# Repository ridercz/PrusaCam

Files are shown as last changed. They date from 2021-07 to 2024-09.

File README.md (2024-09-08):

# PrusaCAM Timelapse Trigger

This is project for making timelapse photos of 3D printing using a common mobile phone, triggered by the printer itself using Bluetooth.

* [Prusa MK3 family](MK3) has some GPIO pins available that can be controlled using G-Code.
* [Prusa MK4 family](MK4) has I2C expansion port to which a [special board](https://help.prusa3d.com/article/gpio-module_734695) can be connected.

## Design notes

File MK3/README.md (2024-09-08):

# PrusaCam for MK3

PrusaCam for MK3 is solution for controlling mobile phones as timelapse cameras from **Prusa MK3** 3D printer by Prusa Research.

> Please note that if you have printer with the xBuddy board (MK3.5 and above), you have to use the MK4 version, not this one.

* **[PrusaCam Feather BT](PrusaCamFeatherBT)** is Bluetooth LE trigger for controlling cellphone cameras, based on _Adafruit Feather 32u4 Bluefruit LE_ board.
* **[PrusaCam ESP32 BT](PrusaCamESP32BT)** is another Bluetooth LE trigger, this time based on ESP32, which is cheaper and more easily available than the Adafruit Feather**.
* **[PrusaCAM USB](PrusaCamUSB)** is smartphone camera controller that emulates USB keyboard.

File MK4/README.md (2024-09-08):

# PrusaCam for MK4

PrusaCam for MK4 is solution for controlling mobile phones as timelapse cameras from **Prusa MK3** 3D printer by Prusa Research. This device will act as remote shutter (Bluetooth keyboard) for the mobile phone camera.

# Hardware

* [GPIO "Hackerboard" set](https://www.prusa3d.com/product/gpio-hackerboard-set/).
* Any board with ESP32 chip with Bluetooth LE capability.

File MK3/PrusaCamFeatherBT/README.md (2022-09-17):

# PrusaCam Feather BT

This is Bluetooth LE trigger for controlling cellphone cameras, based on [Adafruit Feather 32u4 Bluefruit LE](https://www.adafruit.com/product/2829).

## Instructions

* English: [How to make 3D print time lapses with your smartphone camera](https://blog.prusaprinters.org/how-to-make-3d-print-time-lapses-with-your-smartphone-camera/)
* Česky: [Jak na časosběry 3D tisků s pomocí mobilu](https://josefprusa.cz/jak-na-casosbery-3d-tisku-s-pomoci-mobilu/)

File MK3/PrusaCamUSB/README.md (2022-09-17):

# PrusaCam USB

This is smartphone camera controller that emulates USB keyboard. It's intended for any board that uses **ATmega32u4**, ie. Arduino Leonardo, Pro Micro etc. The [HID Project](https://github.com/NicoHood/HID) library is used to emulate the USB keyboard.

To use it with your cellphone, you need a way to connect your board to your phone. Common solution is "USB OTG adaptor", which will convert the MicroUSB or USB-C port of your phone to common USB type A connector. Then you'll use standard MicroUSB cable to connect the board.

I'm actively developing this project now, documentation coming soon.

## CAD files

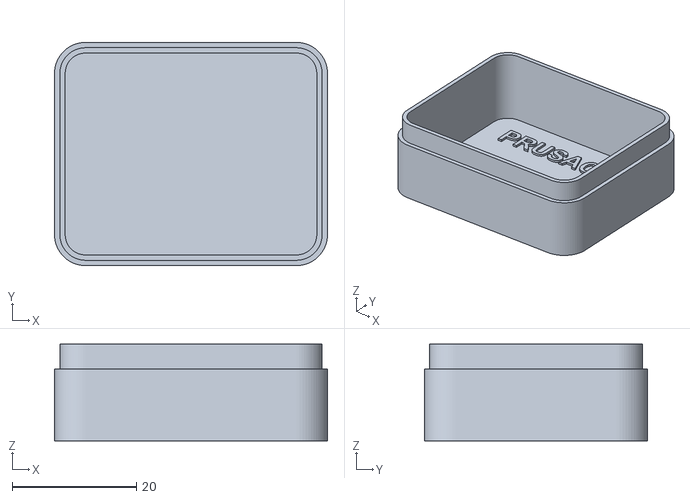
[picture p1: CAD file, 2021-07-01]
MK3/PrusaCamESP32BT/case/PrusaCamESP32BT_bottom.stl
43.9 x 35.9 x 15.6

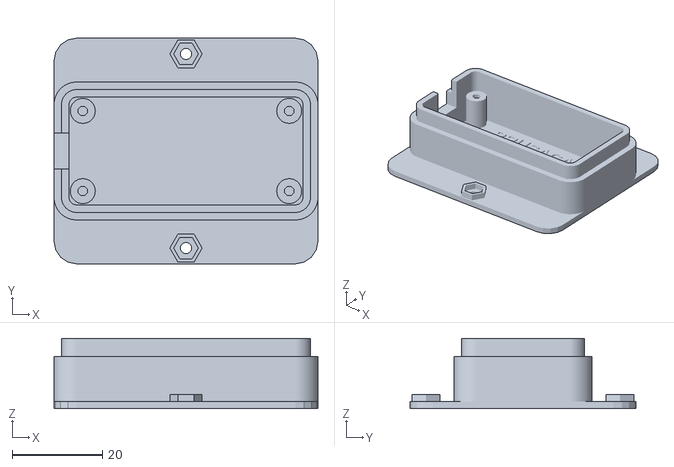
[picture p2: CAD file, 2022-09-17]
MK3/PrusaCamFeatherBT/case/PrusaCamFeatherBT_bottom_with_holder.stl
58.5 x 50.0 x 15.6

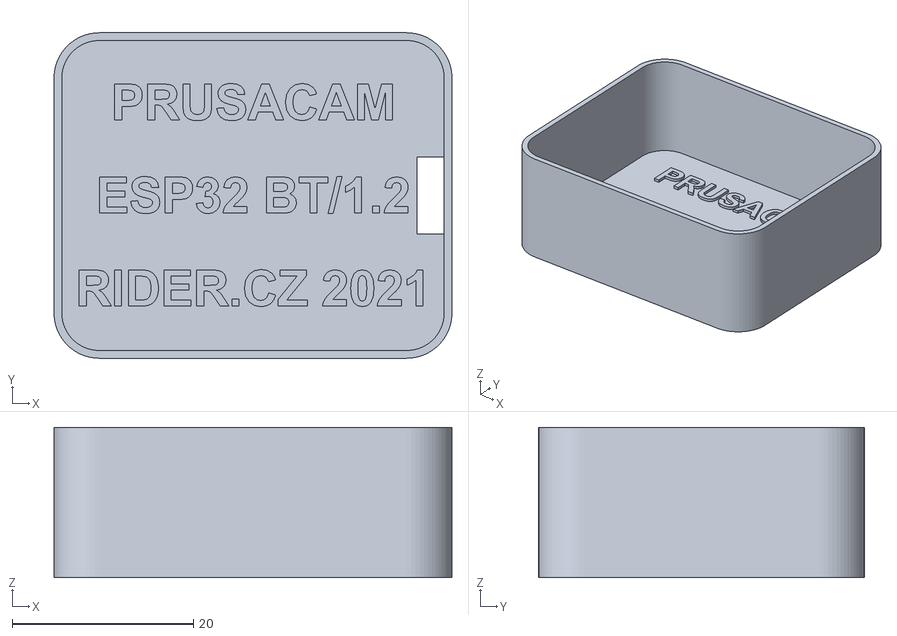
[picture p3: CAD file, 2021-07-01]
MK3/PrusaCamESP32BT/case/PrusaCamESP32BT_top.stl
43.9 x 35.9 x 16.6

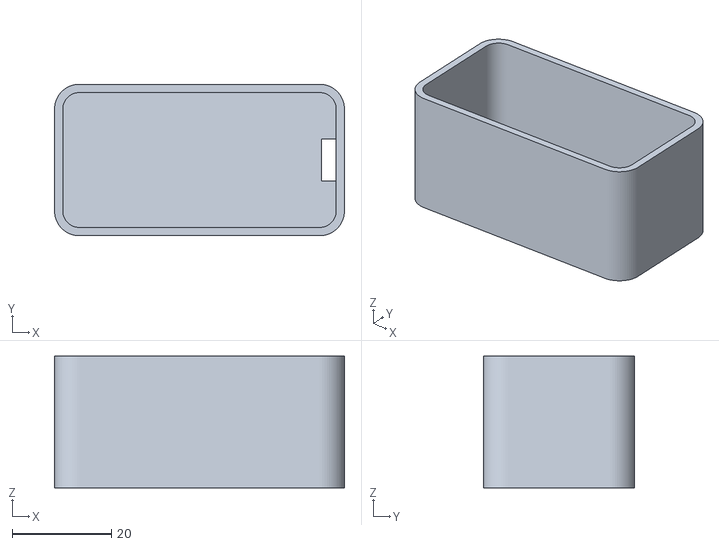
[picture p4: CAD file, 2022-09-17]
MK3/PrusaCamFeatherBT/case/PrusaCamFeatherBT_top.stl
58.5 x 30.5 x 26.6

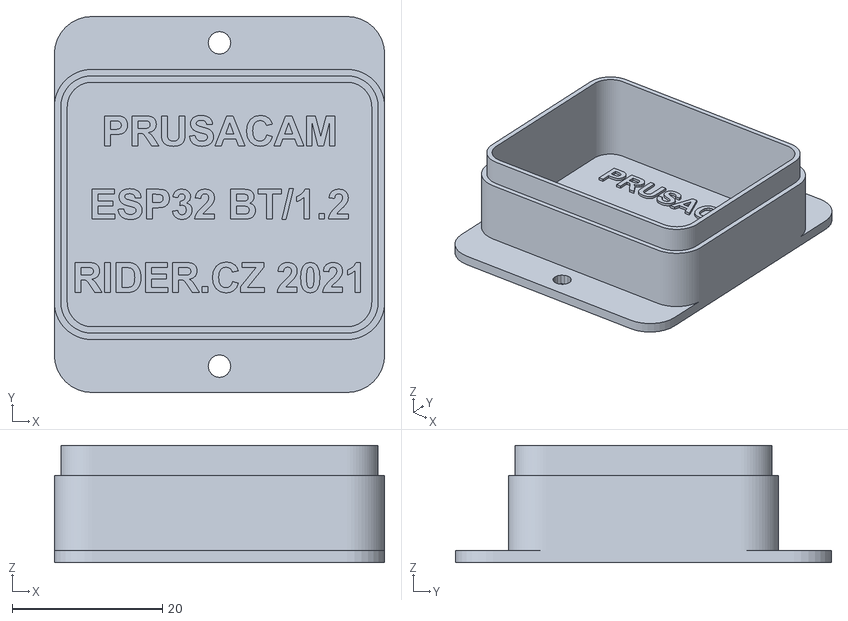
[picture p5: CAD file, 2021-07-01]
MK3/PrusaCamESP32BT/case/PrusaCamESP32BT_bottom_with_holder.stl
43.9 x 50.0 x 15.6

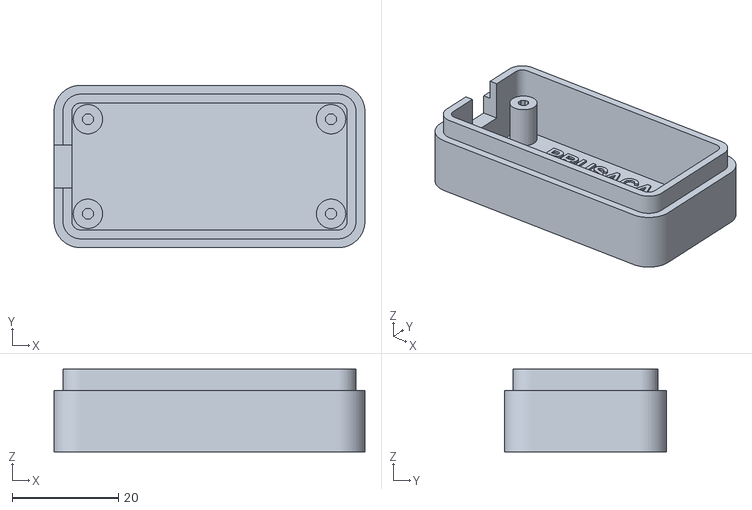
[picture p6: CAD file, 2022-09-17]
MK3/PrusaCamFeatherBT/case/PrusaCamFeatherBT_bottom.stl
58.5 x 30.5 x 15.6

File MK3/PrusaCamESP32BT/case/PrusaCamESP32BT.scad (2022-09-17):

/* [Board dimensions] */
board_size = [40, 32]; 
board_clearance = .5;
cable_size = [3, 8.5];

/* [Top part] */
top_height = 15;

/* [Bottom part] */
bottom_height = 14;
bottom_lip = 4;

/* [Holder plate] */
holder_width = 50;
holder_hole_span = 43;
holder_hole_diameter = 3;
holder_nut_diameter = 5.5;

/* [Hidden] */
wth = 1.60;
wtv = .86;
outer_radius = 5;
vsig = ["PRUSACAM", "ESP32 BT/1.2", "RIDER.CZ 2021"];
$fudge = 1;

// Render all

translate([0, 100]) bottom();
translate([0, 50]) top();
holder();

module holder() {
    holder_size = [
        board_size[0] + board_clearance + 4 * wtv, 
        holder_width, 
        wth
    ];

    bottom(hollow = true);

    difference() {
        // Plate
        translate([-holder_size[0] / 2, -holder_size[1] / 2]) rcube(holder_size, outer_radius, $fn = 32);

        // Screw holes
        for(y = [-holder_hole_span / 2, holder_hole_span / 2]) translate([0, y, -$fudge]) cylinder(d = holder_hole_diameter, h = 2 * wth + 2 * $fudge, $fn = 16);
    }
}

module top() {
    outer_size = [
        board_size[0] + board_clearance + 4 * wtv,
        board_size[1] + board_clearance + 4 * wtv,
        top_height + wth
    ];
    inner_size = [
        board_size[0] + board_clearance + 2 * wtv,
        board_size[1] + board_clearance + 2 * wtv,
        outer_size[2]
    ];
    inner_radius = outer_radius - wtv;

    // Main shape
    difference() {
        // Outer shape
        translate([-outer_size[0] / 2, -outer_size[1] / 2]) rcube(outer_size, outer_radius, $fn = 64);

        // Main hole
        translate([-inner_size[0] / 2, -inner_size[1] / 2, wth]) rcube(inner_size, inner_radius, $fn = 64);

        // Cable hole
        translate([inner_size[0] / 2 - cable_size[0], -cable_size[1] / 2, -$fudge]) cube([cable_size[0], cable_size[1], wth + 2 * $fudge]);
    }

    // Signature
    linear_extrude(wth + .4) {
        translate([0, inner_size[1] * +.3]) text(text = vsig[0], font = "Arial:bold", size = 4, halign = "center", valign = "center");
        text(text = vsig[1], font = "Arial:bold", size = 4, halign = "center", valign = "center");
        translate([0, inner_size[1] * -.3])text(text = vsig[2], font = "Arial:bold", size = 4, halign = "center", valign = "center");
    }
}

module bottom(hollow = false) {
    outer_size = [
        board_size[0] + board_clearance + 4 * wtv,
        board_size[1] + board_clearance + 4 * wtv,
        bottom_height - bottom_lip + wth
    ];
    inner_size = [
        board_size[0] + board_clearance,
        board_size[1] + board_clearance,
        bottom_height + wth + 2 * $fudge
    ];
    inner_radius = outer_radius - 2 * wtv;
    inner_lip_size = [
        board_size[0] + board_clearance + 2 * wtv,
        board_size[1] + board_clearance + 2 * wtv,
        bottom_height + wth
    ];
    inner_lip_radius = outer_radius - wtv;

    // Main shape
    difference() {
        union() {
            // Outer shape
            translate([-outer_size[0] / 2, -outer_size[1] / 2]) rcube(outer_size, outer_radius, $fn = 64);
            // Lip
            translate([-inner_lip_size[0] / 2, -inner_lip_size[1] / 2]) rcube(inner_lip_size, inner_lip_radius, $fn = 64);
        }

        // Main hole
        if(hollow) {
            translate([-inner_size[0] / 2, -inner_size[1] / 2, -$fudge]) rcube(inner_size, inner_radius, $fn = 64);
        } else {
            translate([-inner_size[0] / 2, -inner_size[1] / 2, wth]) rcube(inner_size, inner_radius, $fn = 64);
        }

    }

    // Signature
    linear_extrude(wth + .4) {
        translate([0, inner_size[1] * +.3]) text(text = vsig[0], font = "Arial:bold", size = 4, halign = "center", valign = "center");
        text(text = vsig[1], font = "Arial:bold", size = 4, halign = "center", valign = "center");
        translate([0, inner_size[1] * -.3])text(text = vsig[2], font = "Arial:bold", size = 4, halign = "center", valign = "center");
    }
}

module rcube(size, radius) {
    if(!is_list(radius)) {
        // The same radius on all corners
        rcube(size, [radius, radius, radius, radius]);
    } else if(len(radius) == 2) {
        // Different radii on top and bottom
        rcube(size, [radius[0], radius[0], radius[1], radius[1]]);
    } else if(len(radius) == 4) {
        // Different radius on different corners
        hull() {
            // BL
            if(radius[0] == 0) cube([1, 1, size[2]]);
            else translate([radius[0], radius[0]]) cylinder(r = radius[0], h = size[2]);
            // BR
            if(radius[1] == 0) translate([size[0] - 1, 0]) cube([1, 1, size[2]]);
            else translate([size[0] - radius[1], radius[1]]) cylinder(r = radius[1], h = size[2]);
            // TR
            if(radius[2] == 0) translate([size[0] - 1, size[1] - 1])cube([1, 1, size[2]]);
            else translate([size[0] - radius[2], size[1] - radius[2]]) cylinder(r = radius[2], h = size[2]);
            // TL
            if(radius[3] == 0) translate([0, size[1] - 1]) cube([1, 1, size[2]]);
            else translate([radius[3], size[1] - radius[3]]) cylinder(r = radius[3], h = size[2]);
        }
    } else {
        echo("ERROR: Incorrect length of 'radius' parameter. Expecting integer or vector with length 2 or 4.");
    }
}

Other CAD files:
MK3/PrusaCamFeatherBT/case/PrusaCamFeatherBT.scad

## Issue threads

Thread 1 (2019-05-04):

tried to upload to my new feather board and i get errors

mpkottawa, 2019-05-04:
the start, it says
#include <Arduino.h>
#include <SPI.h>
#include "Adafruit_BLE.h"
#include "Adafruit_BluefruitLE_SPI.h"
#include "PrusaCamConfig.h"

the only file it has is PrusaCamConfig.h.    i get Adafruit_BLE.h: No such file or directory

ridercz, 2019-05-04:
You don't have the `Adafruit BLEFirmata` library installed. Follow instructions available [here](https://blog.prusaprinters.org/how-to-make-3d-print-time-lapses-with-your-smartphone-camera/).

mpkottawa, 2019-05-04:
ok, i had that library downloaded but i didnt actually click it to include
it.   now, im getting:

 Adafruit_BLE.h:42:35: error: utility/common_header.h: No such file or
directory, in the adafruit_ble.h tab.

On Sat, May 4, 2019 at 6:35 AM Michal Altair Valášek <
notifications@github.com> wrote:

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

Closed 2019-05-04.

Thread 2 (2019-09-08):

Adafruit too sensitive sensing false trigger

MikeThomas123456, 2019-09-08:
I’m encountering an issue where the Feather is detecting false triggers and signaling the shutter every 10s (the min interval). At first thought it was a bad board. New board, same problem. Switched trigger to pin 6, same problem. Saw a note on one of the adafruit forums about a similar issue and it’s suggested to install a pulldown resistor to pull the pin to ground when not triggered.

Does the einsy board have an option to pull the pin to ground when not triggered or would an external pulldown resistor be the best option?

MontesDesigns, 2025-01-22:
Hey @MikeThomas123456 were you able to figure this out?

MontesDesigns, 2025-01-23:
@ridercz it seems to be only happening just before the first command is sent from the printer to the adafruit after the first signal is sent it works as expected. After the print, it seems to trigger the pin again every 10s it can be annoying.

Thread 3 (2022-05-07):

Issue only when using bluetooth + trigger (PrusaCamFeatherBT.ino)

stevenbennett, 2022-05-07:
I'm running into an issue when trying to use a bluetooth connection combined with the `USE_TRIGGER` configuration. I can get these to work independently (over bluetooth using `USE_INTERVAL`, and over USB using the gcode trigger and [PrusaCamUSB.ino](https://github.com/ridercz/PrusaCam/blob/master/PrusaCamUSB/PrusaCamUSB.ino) script) but can't get them working together.

I can confirm that the event is being triggered correctly in the gcode and pin 5 is being triggered as expected (I can see the light flashing on the board during the "after layer change" event) but it's never able to send the command to the paired phone (even though the phone is definitely paired (indicated on the board) and works as expected in `USE_INTERVAL` mode.)

I'm not sure where the issue stems from since both modes use the same `pressShutter` function, perhaps it has something to do with the `waitForOK` command  timing out? (In the serial monitor I can see the "Failed! maybe not paired" error triggering whenever the event is triggered)

Any ideas here? Are there any differences between how the command is sent to the paired device using the `USE_TRIGGER` mode vs `USE_INTERVAL`?

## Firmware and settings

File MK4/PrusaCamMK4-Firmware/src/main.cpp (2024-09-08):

/* Altairis PrusaCam MK4 ESP32 BT version 4.0.0 (2024-09-08)
   Copyright (c) Michal A. Valasek - Altairis, 2021-2024
   Licensed under terms of the MIT License.
   www.rider.cz | www.altairis.cz | github.com/ridercz/PrusaCam
*/

#include <Arduino.h>
#include <BleKeyboard.h>

#define LED_PIN 8                       // GPIO pin for LED
#define LED_ON LOW                      // LED is on when LOW
#define LED_OFF HIGH                    // LED is off when HIGH
#define TRIGGER_PIN 5                   // GPIO pin used to trigger
#define TRIGGER_ON_LH true              // trigger on rising edge
#define TRIGGER_ON_HL false             // trigger on falling edge
#define TRIGGER_WAIT 500                // wait after trigger (ms)
#define INITIAL_DELAY 1000              // ignore pin changes for n miliseconds after start
#define SHUTTER_KEY KEY_MEDIA_VOLUME_UP // KEY_MEDIA_VOLUME_UP for Android, KEY_RETURN for Windows Phone
#define PRODUCT_NAME "PrusaCam MK4"     // BLE device name
#define PRODUCT_VERSION "4.0.0"         // BLE device version
#define PRODUCT_MANUFACTURER "Altairis" // BLE device manufacturer

BleKeyboard bleKeyboard(PRODUCT_NAME, PRODUCT_MANUFACTURER);
bool lastTriggerState;
bool delay_passed = false;

void pressShutter()
{
  // Turn on LED
  digitalWrite(LED_PIN, LED_ON);

  // Pres shutter
  if (bleKeyboard.isConnected())
  {
    Serial.println("Pressing shutter...");
    bleKeyboard.write(SHUTTER_KEY);
  }
  else
  {
    Serial.println("Would press shutter but keyboard is not connected.");
  }

  // Wait for a while and then turn off LED
  delay(TRIGGER_WAIT);
  digitalWrite(LED_PIN, LED_OFF);
}

void setup()
{
  // Show header
  Serial.begin(9600);
  Serial.println();
  Serial.println();
  Serial.println(PRODUCT_NAME " version " PRODUCT_VERSION);
  Serial.println("Copyright (c) Michal A. Valasek - Altairis, 2021-2024");
  Serial.println("www.rider.cz | www.altair.blog | github.com/ridercz/PrusaCam");
  Serial.println();

  // Display configuration
  Serial.print("Pin number: ");
  Serial.println(TRIGGER_PIN);
  if (TRIGGER_ON_LH)
    Serial.println("Will trigger on L->H.");
  if (TRIGGER_ON_HL)
    Serial.println("Will trigger on H->L.");
  if (!(TRIGGER_ON_LH || TRIGGER_ON_HL))
    Serial.println("Both TRIGGER_ON_LH and TRIGGER_ON_HL are disabled. The device will do nothing.");
  Serial.println();

  // Start BLE keyboard
  bleKeyboard.begin();

  // Configure trigger pin
  pinMode(TRIGGER_PIN, INPUT);
  lastTriggerState = digitalRead(TRIGGER_PIN);

  // Turn on LED
  pinMode(LED_PIN, OUTPUT);
  digitalWrite(LED_PIN, LED_ON);
}

void loop()
{
  // Check if initial delay had already passed
  if (!delay_passed && millis() > INITIAL_DELAY)
  {
    delay_passed = true;
    digitalWrite(LED_PIN, LED_OFF);
  }
  if (!delay_passed)
    return;

  // Check if we have state change
  bool currentTriggerState = digitalRead(TRIGGER_PIN);
  if (lastTriggerState == currentTriggerState)
    return;

  // Press shutter on rising/falling edge
  if (currentTriggerState && TRIGGER_ON_LH)
    pressShutter();
  if (!currentTriggerState && TRIGGER_ON_HL)
    pressShutter();

  // Remember the state
  lastTriggerState = currentTriggerState;
}

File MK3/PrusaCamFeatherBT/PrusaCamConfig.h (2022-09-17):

/* General configuration
   ---------------------
   INITIAL_DELAY = delay after reset to initialize serial port in ms
   PERFORM_FACTORY_RESET = define to perform BT module factory reset on restart
   SHUTTER_MIN_INTERVAL = minimum interval between shutter presses
*/
#define INITIAL_DELAY                       1000 // ms
//#define PERFORM_FACTORY_RESET
#define SHUTTER_MIN_INTERVAL                10000 // ms

/* Interval shooting feature configuration
   ---------------------------------------
   USE_INTERVAL = define to enable interval shooting
   INTERVAL_DOT = show "." on serial every X ms
   INTERVAL_SHUTTER = press shutter every X ms
*/
//#define USE_INTERVAL
#define INTERVAL_SHUTTER                    30000 // ms

/* Trigger pin feature configuration
   ---------------------------------
   USE_TRIGGER = define to enable triggered shooting
   TRIGGER_ON_LH = true to trigger on switching from low to high
   TRIGGER_ON_HL = true to trigger on switching from high to low
   TRIGGER_PIN = GPIO pin used for trigger
*/
#define USE_TRIGGER
#define TRIGGER_PIN                         5
#define TRIGGER_ON_LH                       true
#define TRIGGER_ON_HL                       false

/* Bluefruit BLE module configuration
   ----------------------------------
   If you use the recommended board Adafruit Feather 32u4 Bluefruit LE,
   (product #2829), then do not modify anything below -- these settings 
   are required for this board.
*/
#define BLUEFRUIT_MINIMUM_FIRMWARE_VERSION  "0.6.6"
#define BLUEFRUIT_SPI_CS                    8
#define BLUEFRUIT_SPI_IRQ                   7
#define BLUEFRUIT_SPI_RST                   4
#define BLUEFRUIT_VERBOSE_MODE              false

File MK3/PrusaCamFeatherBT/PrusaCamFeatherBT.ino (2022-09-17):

/* Altairis PrusaCam Feather BT version 1.0.0 (2019-03-29)
   Copyright (c) Michal A. Valasek - Altairis, 2019
   Licensed under terms of the MIT License.
   www.rider.cz | www.altairis.cz | github.com/ridercz/PrusaCam
*/

#include <Arduino.h>
#include <SPI.h>
#include "Adafruit_BLE.h"
#include "Adafruit_BluefruitLE_SPI.h"
#include "PrusaCamConfig.h"

Adafruit_BluefruitLE_SPI ble(BLUEFRUIT_SPI_CS, BLUEFRUIT_SPI_IRQ, BLUEFRUIT_SPI_RST);
bool serialAvailable = false;
unsigned long nextShutterMin = 0;

#ifdef USE_INTERVAL
unsigned long nextShutterMillis = 0;
#endif

#ifdef USE_TRIGGER
bool lastTriggerState = false;
#endif

void setup() {
  // Turn on LED during initialization
  pinMode(LED_BUILTIN, OUTPUT);
  digitalWrite(LED_BUILTIN, true);

  // Initialize serial port
  Serial.begin(9600);
  while (true) {
    if (Serial) {
      serialAvailable = true;
      break;
    }
    if (millis() > INITIAL_DELAY) break;
  }

  logPrintLn(F("Altairis PrusaCam Feather BT version 1.0.0"));
  logPrintLn(F("Copyright (c) Michal A. Valasek - Altairis, 2019"));
  logPrintLn(F("              www.rider.cz | www.altairis.cz | github.com/ridercz/PrusaCam"));
  logPrintLn();

  // Initialize Bluetooth
  initBLE();

  // Check if there is either interval or trigger
  bool hasSomethigToRunOn = false;

#ifdef USE_TRIGGER
  logPrint(F("Trigger enabled on pin "));
  logPrintLn(TRIGGER_PIN);
  pinMode(TRIGGER_PIN, INPUT);
  if (TRIGGER_ON_LH || TRIGGER_ON_HL) {
    if (TRIGGER_ON_LH) logPrintLn(F("Trigger on LH enabled."));
    if (TRIGGER_ON_HL) logPrintLn(F("Trigger on HL enabled."));
    hasSomethigToRunOn = true;
  } else {
    logPrintLn(F("WARNING: Neither TRIGGER_ON_LH nor TRIGGER_ON_HL is set to true. Trigger is effectively disabled."));
  }
#endif

#ifdef USE_INTERVAL
  logPrint(F("Inteval enabled, time (ms) = "));
  logPrintLn(INTERVAL_SHUTTER);
  hasSomethigToRunOn = true;
#endif

  if (!hasSomethigToRunOn) {
    logPrintLn(F("CONFIGURATION ERROR: There are no conditions for shutter defined, so the shutter will never be pressed."));
    logPrintLn(F("System halted."));
    while (1);
  }

  // Turn off LED
  logPrintLn(F("Initialization done, system ready."));
  digitalWrite(LED_BUILTIN, false);
}

void loop() {
#ifdef USE_TRIGGER
  bool currentTriggerState = digitalRead(TRIGGER_PIN);
  if (lastTriggerState != currentTriggerState) {
    if (TRIGGER_ON_LH && currentTriggerState) {
      logPrint("Trigger (LH) detected: ");
      pressShutter();
    }
    if (TRIGGER_ON_HL && !currentTriggerState) {
      logPrint("Trigger (HL) detected: ");
      pressShutter();
    }
    lastTriggerState = currentTriggerState;
  }
#endif

#ifdef USE_INTERVAL
  // Press shutter every INTERVAL_SHUTTER ms
  if (millis() >= nextShutterMillis) {
    pressShutter();
    logPrintLn(F("Waiting..."));
    nextShutterMillis = millis() + INTERVAL_SHUTTER;
  }
#endif
}

void initBLE() {
  logPrint(F("Initializing the Bluetooth module..."));
  if (!ble.begin(BLUEFRUIT_VERBOSE_MODE)) {
    logPrintLn(F("Failed!"));
    while (1);
  }
  logPrintLn(F("OK"));

  if (serialAvailable) {
    // Disable command echo
    ble.echo(false);
    // Display module info
    ble.info();
  }

#ifdef PERFORM_FACTORY_RESET
  logPrint(F("Performing a factory reset..."));
  if (!ble.factoryReset()) {
    logPrintLn(F("Failed!"));
    while (1);
  }
  logPrintLn(F("OK"));
#endif

  // Firmware version 0.6.6+ required
  if (!ble.isVersionAtLeast(BLUEFRUIT_MINIMUM_FIRMWARE_VERSION)) {
    logPrintLn(F("This sketch requires firmware version "BLUEFRUIT_MINIMUM_FIRMWARE_VERSION" or higher!"));
    while (1);
  }

  logPrint(F("Setting device name to 'Altairis PrusaCam Feather BT'..."));
  if (!ble.sendCommandCheckOK(F("AT+GAPDEVNAME=Altairis PrusaCam Feather BT"))) {
    logPrintLn(F("Failed!"));
    while (1);
  }
  logPrintLn(F("OK"));

  logPrint(F("Enabling HID Services..."));
  if (!ble.sendCommandCheckOK(F("AT+BLEHIDEN=On"))) {
    logPrintLn(F("Failed!"));
    while (1);
  }
  logPrintLn(F("OK"));

  logPrint(F("Applying changes..."));
  if (!ble.reset()) {
    logPrintLn(F("Failed!"));
    while (1);
  }
  logPrintLn(F("OK"));
}

void pressShutter() {
  if (millis() < nextShutterMin) {
    logPrintLn(F("Ignoring shutter request, too early after previous one."));
    return;
  }

  // Turn on LED during shutter press
  digitalWrite(LED_BUILTIN, true);

  // Send VOLUME+
  logPrint(F("Pressing shutter..."));
  ble.println(F("AT+BleHidControlKey=VOLUME+"));
  if (!ble.waitForOK()) {
    logPrintLn(F("Failed! (maybe not paired?)"));
  } else {
    logPrintLn(F("OK"));
  }

  // Turn off LED
  digitalWrite(LED_BUILTIN, false);

  // Set minimum time for next shutter
  nextShutterMin = millis() + SHUTTER_MIN_INTERVAL;
}

void logPrintLn() {
  if (!serialAvailable) return;
  Serial.println();
}

void logPrintLn(char* s) {
  if (!serialAvailable) return;
  Serial.println(s);
}

void logPrintLn(String s) {
  if (!serialAvailable) return;
  Serial.println(s);
}

void logPrint(String s) {
  if (!serialAvailable) return;
  Serial.print(s);
}

void logPrint(char* s) {
  if (!serialAvailable) return;
  Serial.print(s);
}

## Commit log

2019-03-19 Case v1.0
    [PrusaCamFeatherBT.scad, PrusaCamFeatherBT_bottom.stl, PrusaCamFeatherBT_top.stl]
2019-03-19 Made lip higher
    [PrusaCamFeatherBT.scad]
2019-03-19 Tweaked dimensions and added printer frame holder
    [PrusaCamFeatherBT.scad, PrusaCamFeatherBT_bottom.stl, PrusaCamFeatherBT_bottom_with_holder.stl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]
2019-03-28 Moved casing to separate folder
    [PrusaCamFeatherBT.scad, PrusaCamFeatherBT_bottom.stl, PrusaCamFeatherBT_bottom_with_holder.stl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]
2019-03-29 Tweaked case dimensions
    [PrusaCamFeatherBT.scad, PrusaCamFeatherBT_bottom.stl, PrusaCamFeatherBT_bottom_with_holder.stl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]
2021-05-21 Use is_list available in current OpenSCAD.
    [PrusaCamFeatherBT.scad]
2021-05-21 Add ESP32 BT version code
2021-06-19 Add case
    [PrusaCamESP32BT.scad, PrusaCamESP32BT_bottom.stl, PrusaCamESP32BT_bottom_with_holder.stl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]
2021-07-01 Update case based on prototype
    [PrusaCamESP32BT.scad, PrusaCamESP32BT_bottom.stl, PrusaCamESP32BT_bottom_with_holder.stl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]
2022-09-17 Add link to ESP32BT version.
2022-09-17 Switch to CRLF line ends.
    [PrusaCamESP32BT.scad, PrusaCamFeatherBT.scad, PrusaCamFeatherBT_bottom.stl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]
2024-09-08 Reorganize folders for MK4 version.
    [PrusaCamESP32BT.scad, PrusaCamESP32BT_bottom.stl, PrusaCamESP32BT_bottom_with_holder.stl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]
